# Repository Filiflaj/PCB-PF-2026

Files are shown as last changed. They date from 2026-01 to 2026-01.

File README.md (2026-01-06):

# PF 2026 - Sparkling LED Greeting Card

A custom-designed PCB created as a unique "Pour Féliciter 2026" (Happy New Year 2026) greeting card. The board features **39 individually addressable LEDs** arranged to form the text "PF 26", displaying a dynamic, warm fireworks sparkling effect.

This project is built around the **ATmega328P-AU** microcontroller, making it fully compatible with the Arduino ecosystem.

---

## 📷 Preview

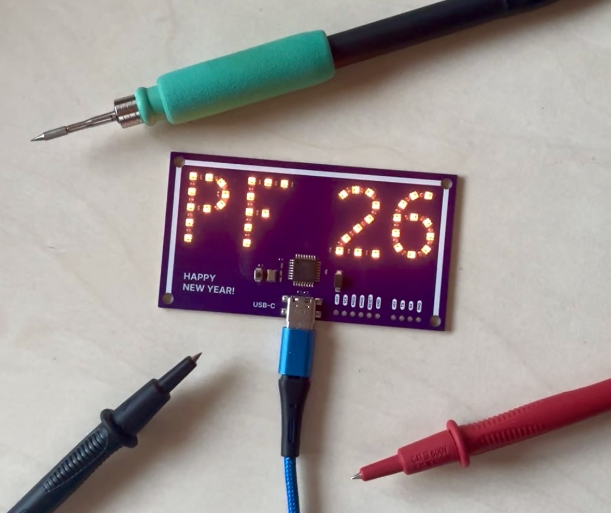
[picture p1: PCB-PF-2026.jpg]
PF 2026 Board Assembled


*Finished and assembled PCB with the sparkling effect.*

---

## ⚡ Technical Specifications

* **MCU:** ATmega328P-AU (8-bit AVR, 16MHz external crystal).
* **LEDs:** 39x WS2812B-2020 (NeoPixel) in a single chain.
* **LED Pin:** Connected to **PD3** (Digital Pin **3** in Arduino IDE).
* **Interfaces:** * Standard **ICSP** header (for bootloader and ISP programming).
    * **UART** header (RX, TX, VCC, GND, DTR) for serial communication and programming.
* **Power:** 5V via USB-C connector (with 5.1k CC resistors for compatibility).

---

## 📂 Project Structure

The repository is divided into two main sections:

### 🛠️ [HW-PF-2026](./HW-PF-2026) (Hardware)
Contains all files necessary for PCB manufacturing and assembly:
* **KiCad Project:** Full schematic and PCB layout files.
* **Schematic:** PDF version for quick reference.
* **Manufacturing:** Gerbers and Drill files.
* **BOM:** Bill of Materials.

### 💻 [FW-PF-2026](./FW-PF-2026) (Firmware)
Contains the Arduino source code:
* **Sparkle Effect:** A gentle, warm-yellow "fireworks" animation with random 1-3 LED bursts and a dim static background.
* **Library dependency:** Requires the `Adafruit_NeoPixel` library.

---

## 🔌 Programming Guide

Since the board does not have an onboard USB-to-Serial converter, you can program it using an **Arduino UNO R3** as an ISP programmer.

### 1. Wiring (Arduino UNO to ICSP)

Connect your Arduino UNO to the ICSP header on the PF 2026 board as follows:

| Arduino UNO (Programmer) | PF 2026 (Target) |
| :--- | :--- |
| 5V | VCC |
| GND | GND |
| Pin 13 | SCK |
| Pin 12 | MISO |
| Pin 11 | MOSI |
| **Pin 10** | **RESET** |

### 2. Burning the Bootloader
1.  Open Arduino IDE.
2.  Go to **File -> Examples -> 11.ArduinoISP -> ArduinoISP** and upload it to your UNO.
3.  Go to **Tools -> Board** and select **Arduino Uno**.
4.  Go to **Tools -> Programmer** and select **Arduino as ISP**.
5.  Click **Tools -> Burn Bootloader**.

### 3. Uploading Firmware
1.  Open the sketch from the `/FW-PF-2026` folder.
2.  Go to **Sketch -> Upload Using Programmer** (or press `Ctrl+Shift+U`).

---

## 👤 Author
**Filip Flajšinger** Created for the 2026 New Year celebrations. 🥂

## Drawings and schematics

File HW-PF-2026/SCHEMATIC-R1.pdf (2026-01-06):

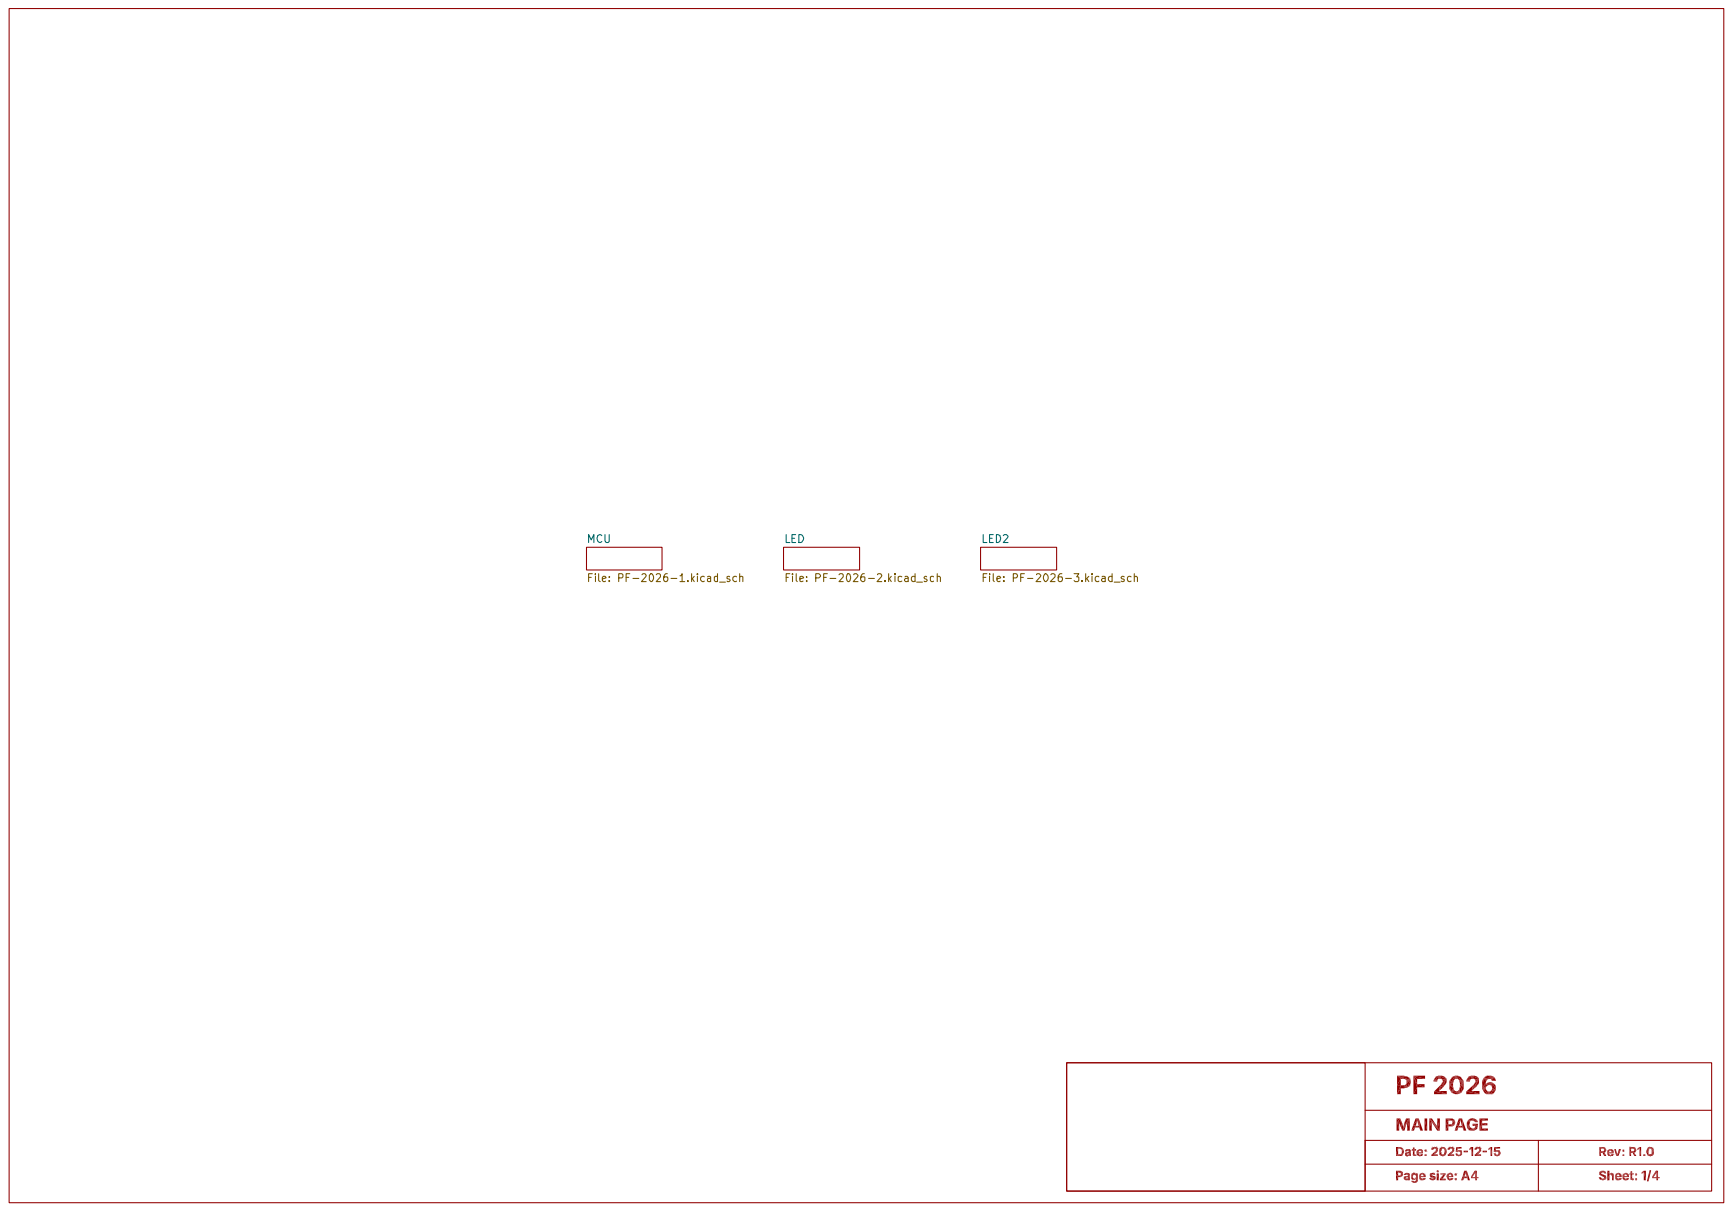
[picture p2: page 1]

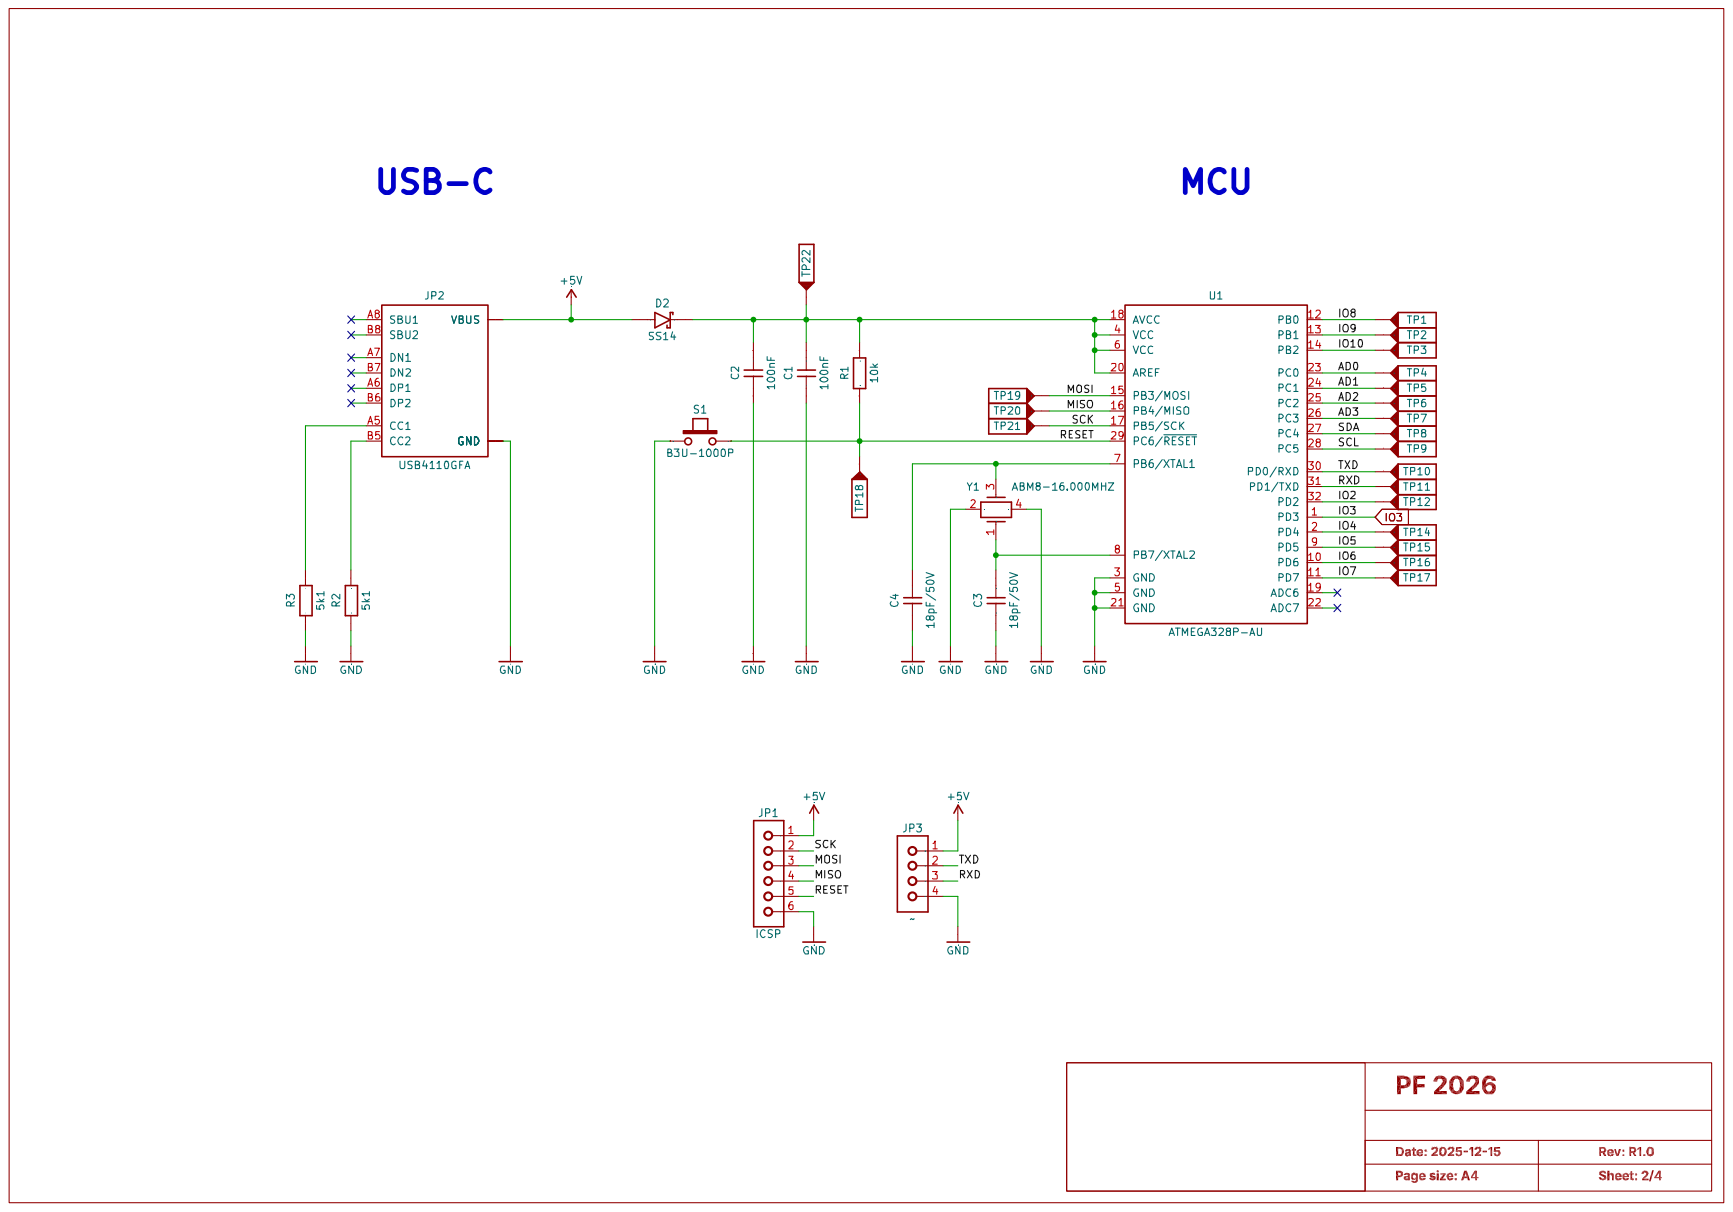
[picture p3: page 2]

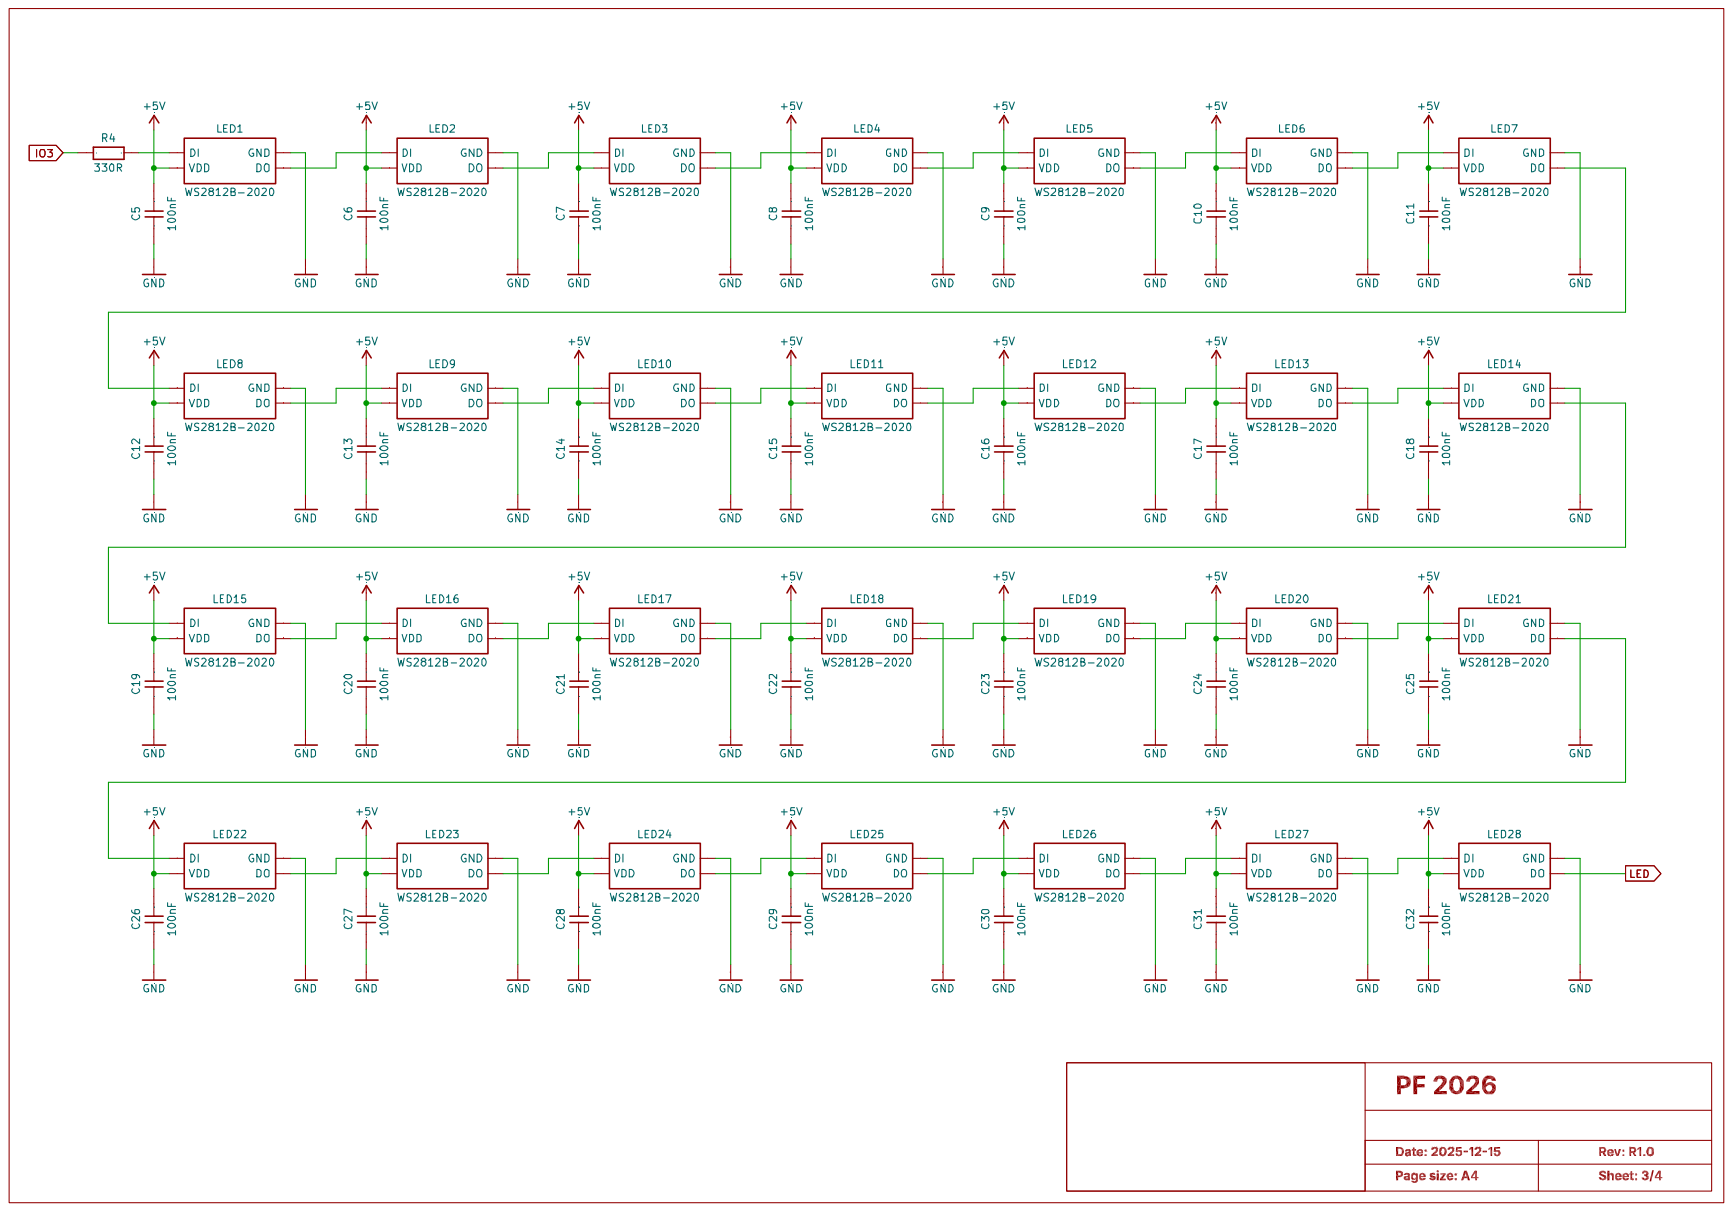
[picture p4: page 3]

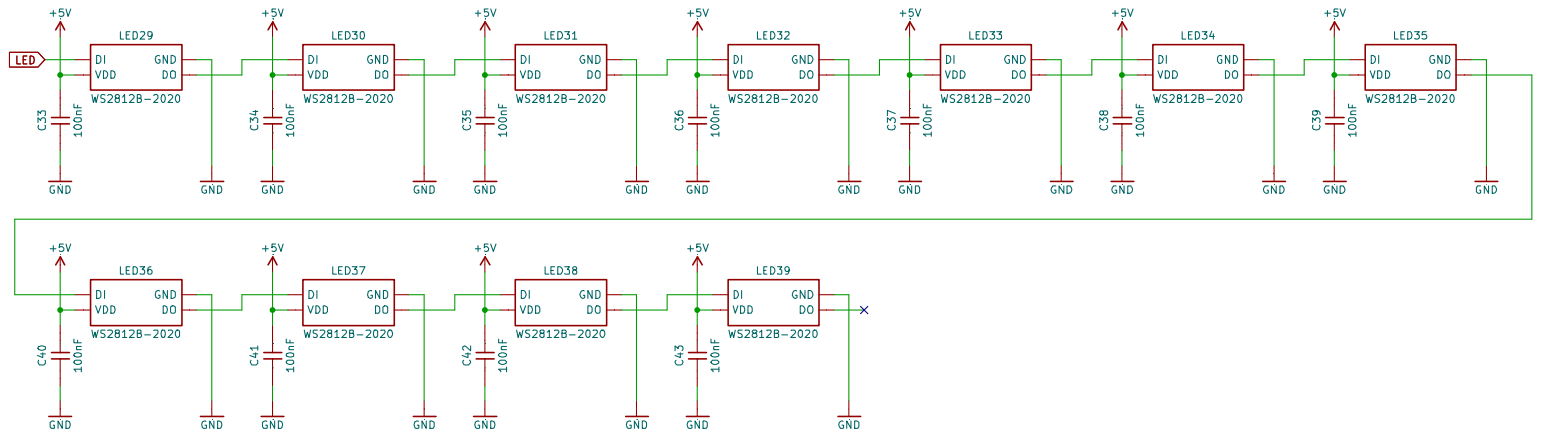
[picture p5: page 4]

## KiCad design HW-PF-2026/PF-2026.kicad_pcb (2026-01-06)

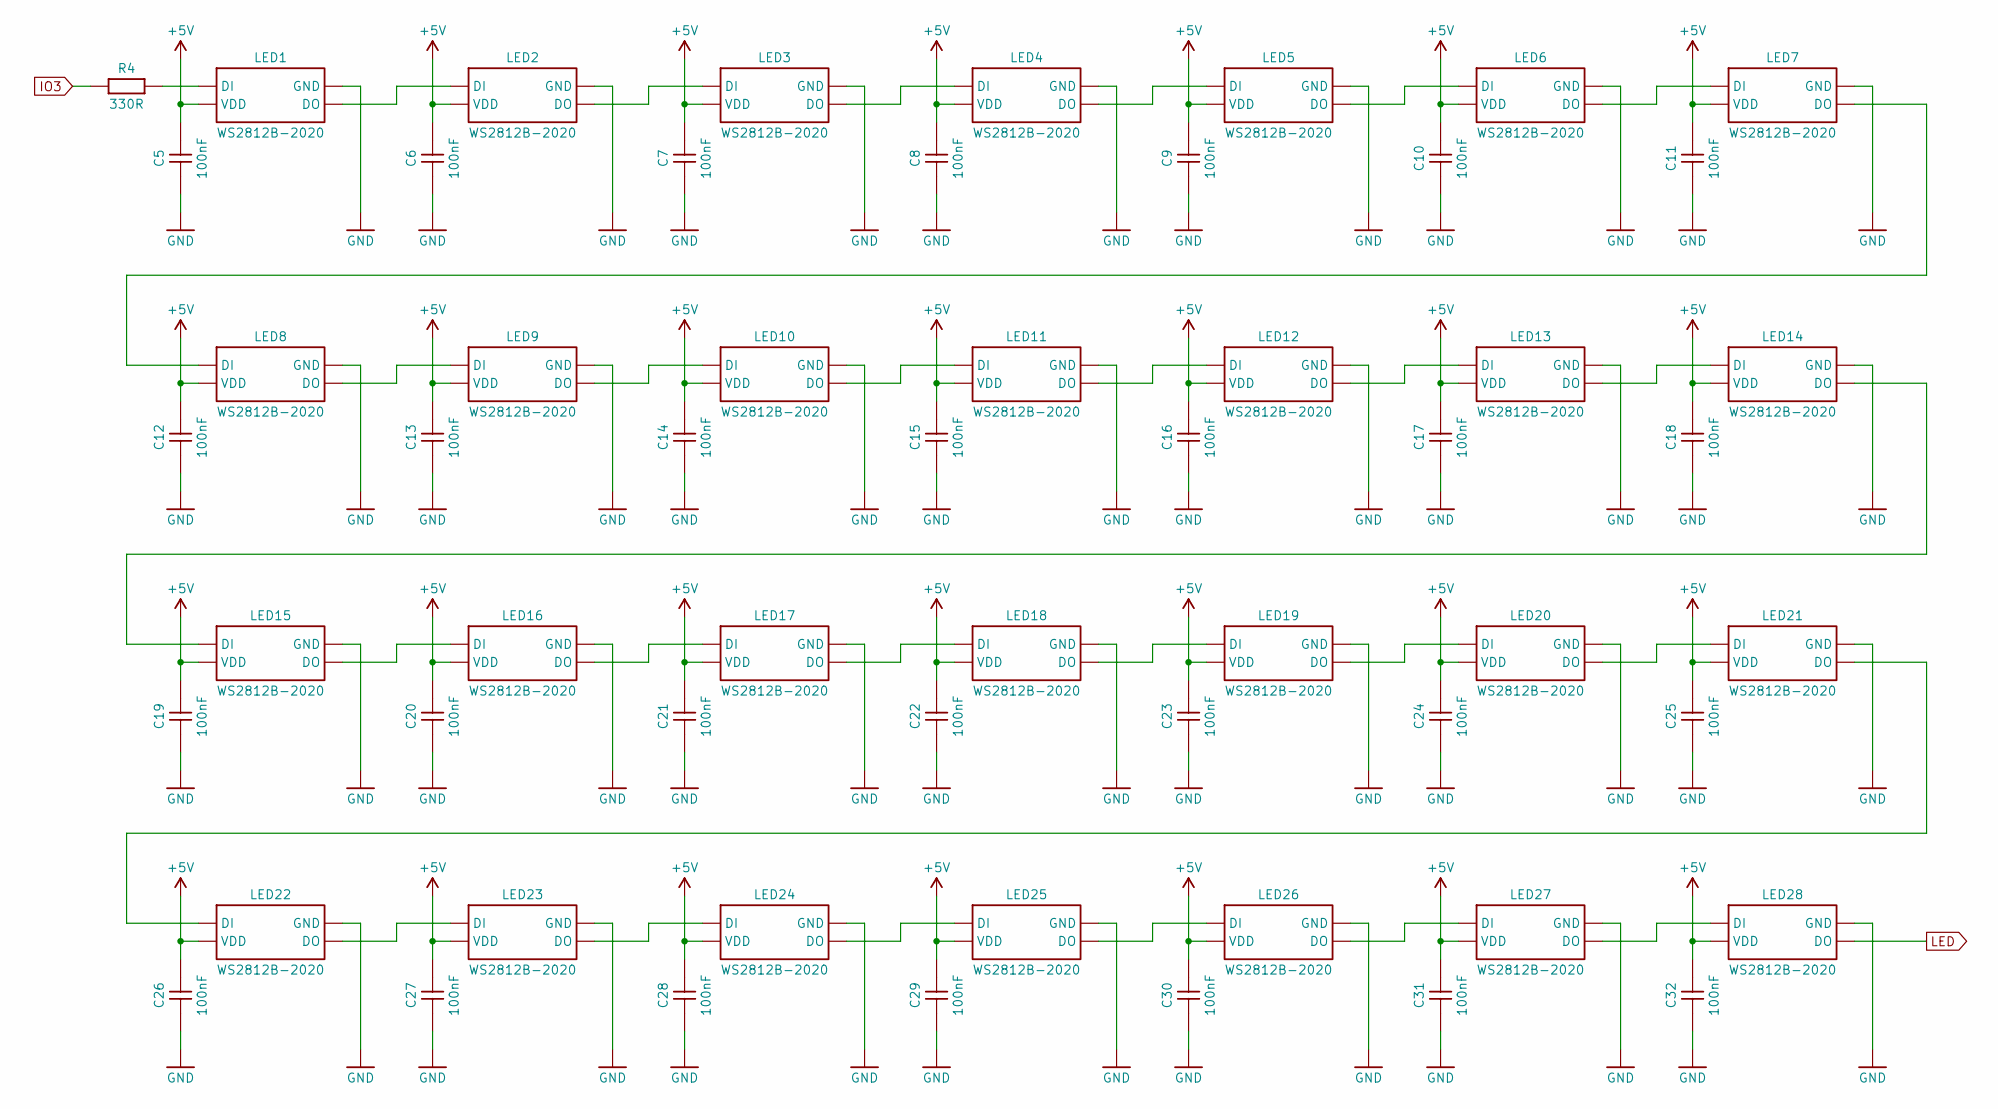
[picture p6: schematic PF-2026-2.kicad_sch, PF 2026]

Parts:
C5, C6, C7, C8, C9, C10, C11, C12, C13, C14, C15, C16, C17, C18, C19, C20, C21, C22, C23, C24, C25, C26, C27, C28, C29, C30, C31, C32: 100nF; CAPACITOR-0402_R
LED1, LED2, LED3, LED4, LED5, LED6, LED7, LED8, LED9, LED10, LED11, LED12, LED13, LED14, LED15, LED16, LED17, LED18, LED19, LED20, LED21, LED22, LED23, LED24, LED25, LED26, LED27, LED28: WS2812B-2020; WS2812B-2020_R; Manufacturer Part Number WS2812B-2020
R4: 330R; RESISTOR-0402_R; Manufacturer Part Number RT0402FRE07330RL

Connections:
+5V: C5.1, C6.1, C7.1, C8.1, C9.1, C10.1, C11.1, C12.1, C13.1, C14.1, C15.1, C16.1, C17.1, C18.1, C19.1, C20.1, C21.1, C22.1, C23.1, C24.1, C25.1, C26.1, C27.1, C28.1, C29.1, C30.1, C31.1, C32.1, LED1.4 (VDD), LED2.4 (VDD), LED3.4 (VDD), LED4.4 (VDD), LED5.4 (VDD), LED6.4 (VDD), LED7.4 (VDD), LED8.4 (VDD), LED9.4 (VDD), LED10.4 (VDD), LED11.4 (VDD), LED12.4 (VDD), LED13.4 (VDD), LED14.4 (VDD), LED15.4 (VDD), LED16.4 (VDD), LED17.4 (VDD), LED18.4 (VDD), LED19.4 (VDD), LED20.4 (VDD), LED21.4 (VDD), LED22.4 (VDD), LED23.4 (VDD), LED24.4 (VDD), LED25.4 (VDD), LED26.4 (VDD), LED27.4 (VDD), LED28.4 (VDD); also elsewhere on the board
GND: C5.2, C6.2, C7.2, C8.2, C9.2, C10.2, C11.2, C12.2, C13.2, C14.2, C15.2, C16.2, C17.2, C18.2, C19.2, C20.2, C21.2, C22.2, C23.2, C24.2, C25.2, C26.2, C27.2, C28.2, C29.2, C30.2, C31.2, C32.2, LED1.2 (GND), LED2.2 (GND), LED3.2 (GND), LED4.2 (GND), LED5.2 (GND), LED6.2 (GND), LED7.2 (GND), LED8.2 (GND), LED9.2 (GND), LED10.2 (GND), LED11.2 (GND), LED12.2 (GND), LED13.2 (GND), LED14.2 (GND), LED15.2 (GND), LED16.2 (GND), LED17.2 (GND), LED18.2 (GND), LED19.2 (GND), LED20.2 (GND), LED21.2 (GND), LED22.2 (GND), LED23.2 (GND), LED24.2 (GND), LED25.2 (GND), LED26.2 (GND), LED27.2 (GND), LED28.2 (GND); also elsewhere on the board
IO3: R4.1; also elsewhere on the board
LED: LED28.1 (DO); also elsewhere on the board
unnamed: LED1.3 (DI), R4.2
unnamed: LED1.1 (DO), LED2.3 (DI)
unnamed: LED2.1 (DO), LED3.3 (DI)
unnamed: LED3.1 (DO), LED4.3 (DI)
unnamed: LED4.1 (DO), LED5.3 (DI)
unnamed: LED5.1 (DO), LED6.3 (DI)
unnamed: LED6.1 (DO), LED7.3 (DI)
unnamed: LED7.1 (DO), LED8.3 (DI)
unnamed: LED8.1 (DO), LED9.3 (DI)
unnamed: LED9.1 (DO), LED10.3 (DI)
unnamed: LED10.1 (DO), LED11.3 (DI)
unnamed: LED11.1 (DO), LED12.3 (DI)
unnamed: LED12.1 (DO), LED13.3 (DI)
unnamed: LED13.1 (DO), LED14.3 (DI)
unnamed: LED14.1 (DO), LED15.3 (DI)
unnamed: LED15.1 (DO), LED16.3 (DI)
unnamed: LED16.1 (DO), LED17.3 (DI)
unnamed: LED17.1 (DO), LED18.3 (DI)
unnamed: LED18.1 (DO), LED19.3 (DI)
unnamed: LED19.1 (DO), LED20.3 (DI)
unnamed: LED20.1 (DO), LED21.3 (DI)
unnamed: LED21.1 (DO), LED22.3 (DI)
unnamed: LED22.1 (DO), LED23.3 (DI)
unnamed: LED23.1 (DO), LED24.3 (DI)
unnamed: LED24.1 (DO), LED25.3 (DI)
unnamed: LED25.1 (DO), LED26.3 (DI)
unnamed: LED26.1 (DO), LED27.3 (DI)
unnamed: LED27.1 (DO), LED28.3 (DI)

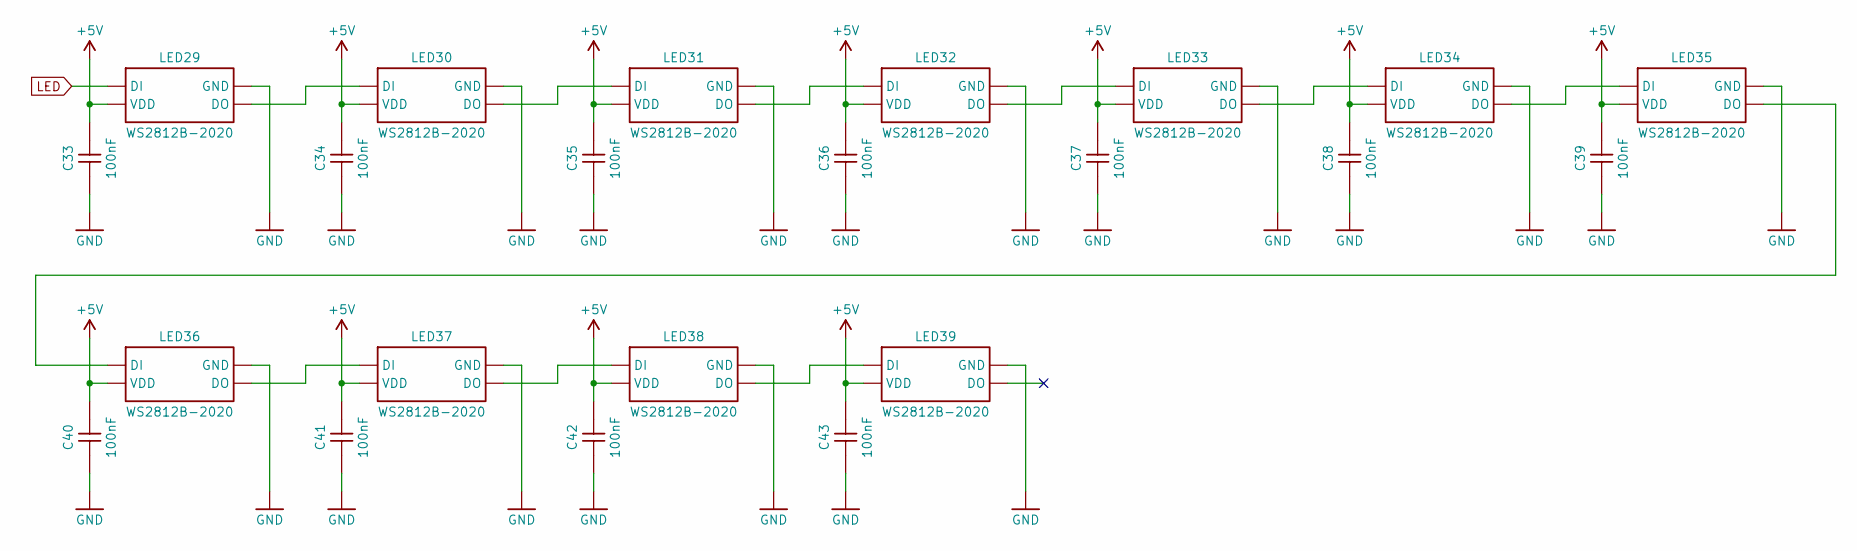
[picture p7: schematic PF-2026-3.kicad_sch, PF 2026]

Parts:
C33, C34, C35, C36, C37, C38, C39, C40, C41, C42, C43: 100nF; CAPACITOR-0402_R
LED29, LED30, LED31, LED32, LED33, LED34, LED35, LED36, LED37, LED38, LED39: WS2812B-2020; WS2812B-2020_R; Manufacturer Part Number WS2812B-2020

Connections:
+5V: C33.1, C34.1, C35.1, C36.1, C37.1, C38.1, C39.1, C40.1, C41.1, C42.1, C43.1, LED29.4 (VDD), LED30.4 (VDD), LED31.4 (VDD), LED32.4 (VDD), LED33.4 (VDD), LED34.4 (VDD), LED35.4 (VDD), LED36.4 (VDD), LED37.4 (VDD), LED38.4 (VDD), LED39.4 (VDD); also elsewhere on the board
GND: C33.2, C34.2, C35.2, C36.2, C37.2, C38.2, C39.2, C40.2, C41.2, C42.2, C43.2, LED29.2 (GND), LED30.2 (GND), LED31.2 (GND), LED32.2 (GND), LED33.2 (GND), LED34.2 (GND), LED35.2 (GND), LED36.2 (GND), LED37.2 (GND), LED38.2 (GND), LED39.2 (GND); also elsewhere on the board
LED: LED29.3 (DI); also elsewhere on the board
unnamed: LED29.1 (DO), LED30.3 (DI)
unnamed: LED30.1 (DO), LED31.3 (DI)
unnamed: LED31.1 (DO), LED32.3 (DI)
unnamed: LED32.1 (DO), LED33.3 (DI)
unnamed: LED33.1 (DO), LED34.3 (DI)
unnamed: LED34.1 (DO), LED35.3 (DI)
unnamed: LED35.1 (DO), LED36.3 (DI)
unnamed: LED36.1 (DO), LED37.3 (DI)
unnamed: LED37.1 (DO), LED38.3 (DI)
unnamed: LED38.1 (DO), LED39.3 (DI)

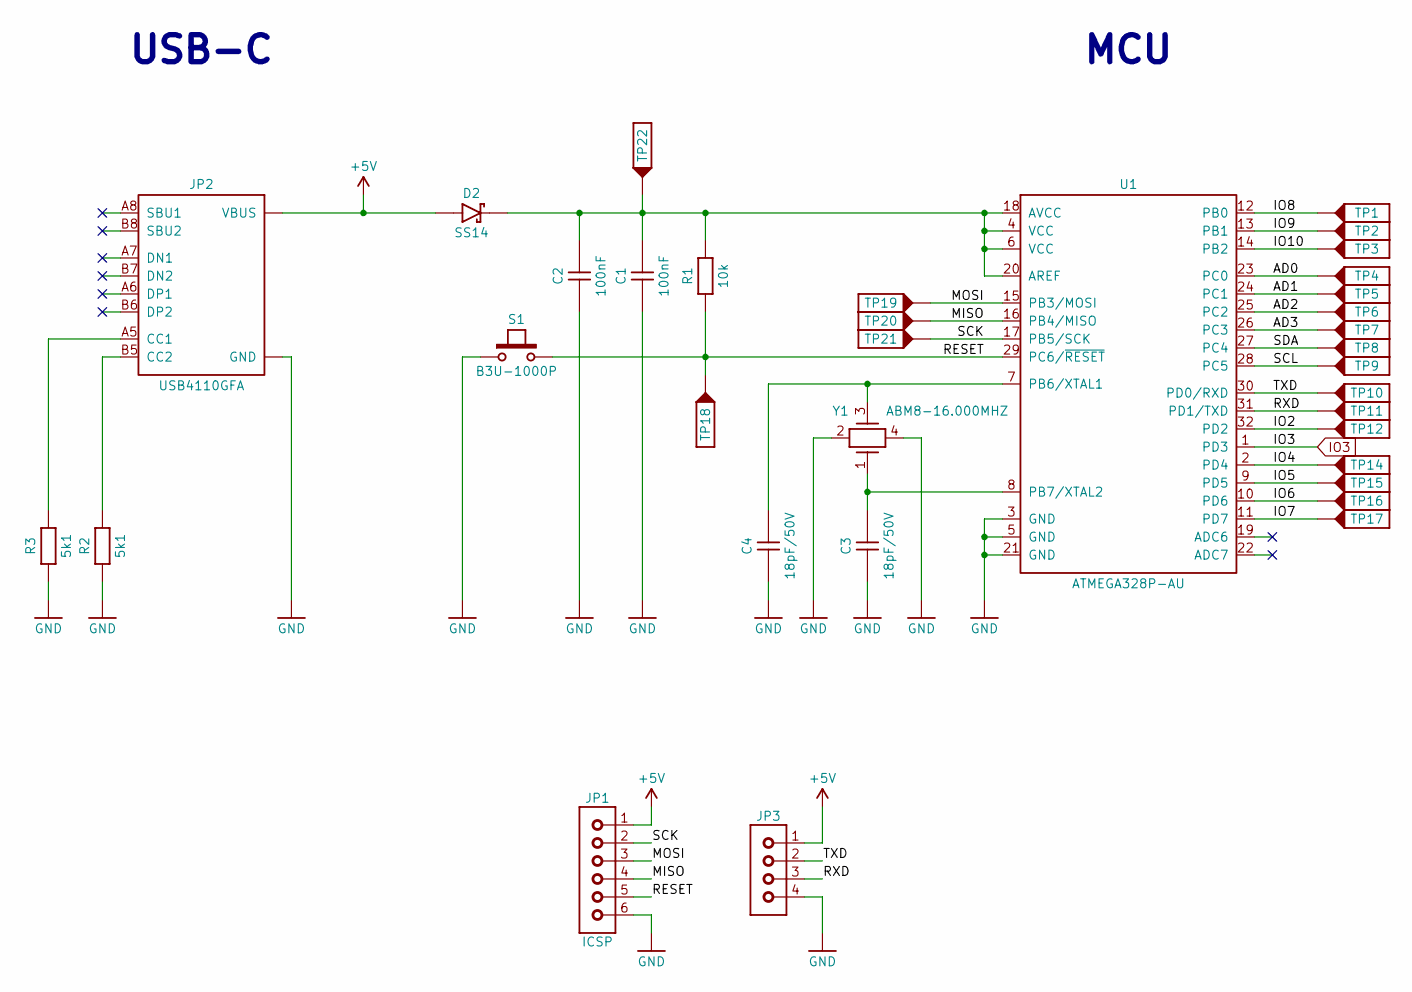
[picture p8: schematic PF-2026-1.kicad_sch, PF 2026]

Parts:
C1, C2: 100nF; CAPACITOR-0402_R
C3, C4: 18pF/50V; CAPACITOR-0402_R; Manufacturer Part Number 04025A180JAT4A
D2: SS14; SS14_R
JP1: ICSP; HEADER-6-PIN-THT; Manufacturer Part Number 61300611121
JP2: USB4110GFA; USB4110GFA_R; Manufacturer Part Number USB4110-GF-A
JP3: HEADER-4-PIN-THT; Manufacturer Part Number 61300411121
R1: 10k; RESISTOR-0402_R; Manufacturer Part Number RT0402FRE0710KL
R2, R3: 5k1; RESISTOR-0402_R
S1: B3U-1000P; B3U-1000P_R; Manufacturer Part Number B3U-1000P
TP1, TP2, TP3, TP4, TP5, TP6, TP7, TP8, TP9, TP10, TP11, TP12, TP14, TP15, TP16, TP17, TP18, TP19, TP20, TP21, TP22: TP-1.0-MM
U1: ATMEGA328P-AU; ATMEGA328P-AU_R
Y1: ABM8-16.000MHZ; ABM8-16.000MHZ-7-1-U-T_R; Manufacturer Part Number ABM8-16.000MHZ-7-1-U-T

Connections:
+5V: D2.2, JP1.1, JP2.A4/B9 (VBUS), JP2.B4/A9 (VBUS), JP3.1; also elsewhere on the board
/MCU/AD0: TP4.0, U1.23 (PC0)
/MCU/AD1: TP5.0, U1.24 (PC1)
/MCU/AD2: TP6.0, U1.25 (PC2)
/MCU/AD3: TP7.0, U1.26 (PC3)
/MCU/IO2: TP12.0, U1.32 (PD2)
/MCU/IO4: TP14.0, U1.2 (PD4)
/MCU/IO5: TP15.0, U1.9 (PD5)
/MCU/IO6: TP16.0, U1.10 (PD6)
/MCU/IO7: TP17.0, U1.11 (PD7)
/MCU/IO8: TP1.0, U1.12 (PB0)
/MCU/IO9: TP2.0, U1.13 (PB1)
/MCU/IO10: TP3.0, U1.14 (PB2)
/MCU/MISO: JP1.4, TP20.0, U1.16 (PB4/MISO)
/MCU/MOSI: JP1.3, TP19.0, U1.15 (PB3/MOSI)
/MCU/RESET: JP1.5, R1.1, S1.2, TP18.0, U1.29 (PC6/~RESET)
/MCU/RXD: JP3.3, TP11.0, U1.31 (PD1/TXD)
/MCU/SCK: JP1.2, TP21.0, U1.17 (PB5/SCK)
/MCU/SCL: TP9.0, U1.28 (PC5)
/MCU/SDA: TP8.0, U1.27 (PC4)
/MCU/TXD: JP3.2, TP10.0, U1.30 (PD0/RXD)
GND: C1.2, C2.2, C3.2, C4.2, JP1.6, JP2.A1/B12 (GND), JP2.B1/A12 (GND), JP2.S1 (GND), JP2.S2 (GND), JP2.S3 (GND), JP2.S4 (GND), JP3.4, R2.2, R3.2, S1.1, U1.3 (GND), U1.5 (GND), U1.21 (GND), Y1.2 (GND1), Y1.4 (GND2); also elsewhere on the board
IO3: U1.1 (PD3); also elsewhere on the board
unnamed: JP2.A5 (CC1), R3.1
unnamed: JP2.B5 (CC2), R2.1
unnamed: C1.1, C2.1, D2.1, R1.2, TP22.0, U1.4 (VCC), U1.6 (VCC), U1.18 (AVCC), U1.20 (AREF)
unnamed: C4.1, U1.7 (PB6/XTAL1), Y1.3 (Y2)
unnamed: C3.1, U1.8 (PB7/XTAL2), Y1.1 (Y1)

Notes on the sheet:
MCU
USB-C

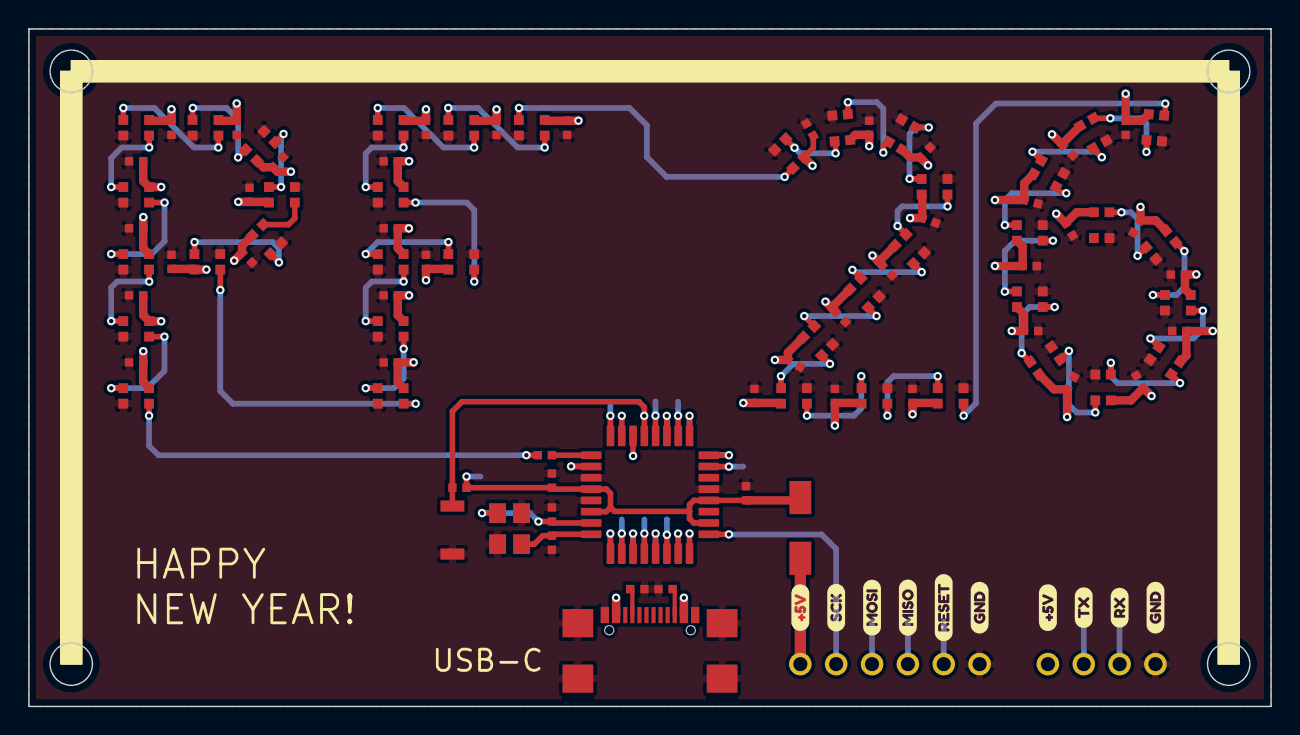
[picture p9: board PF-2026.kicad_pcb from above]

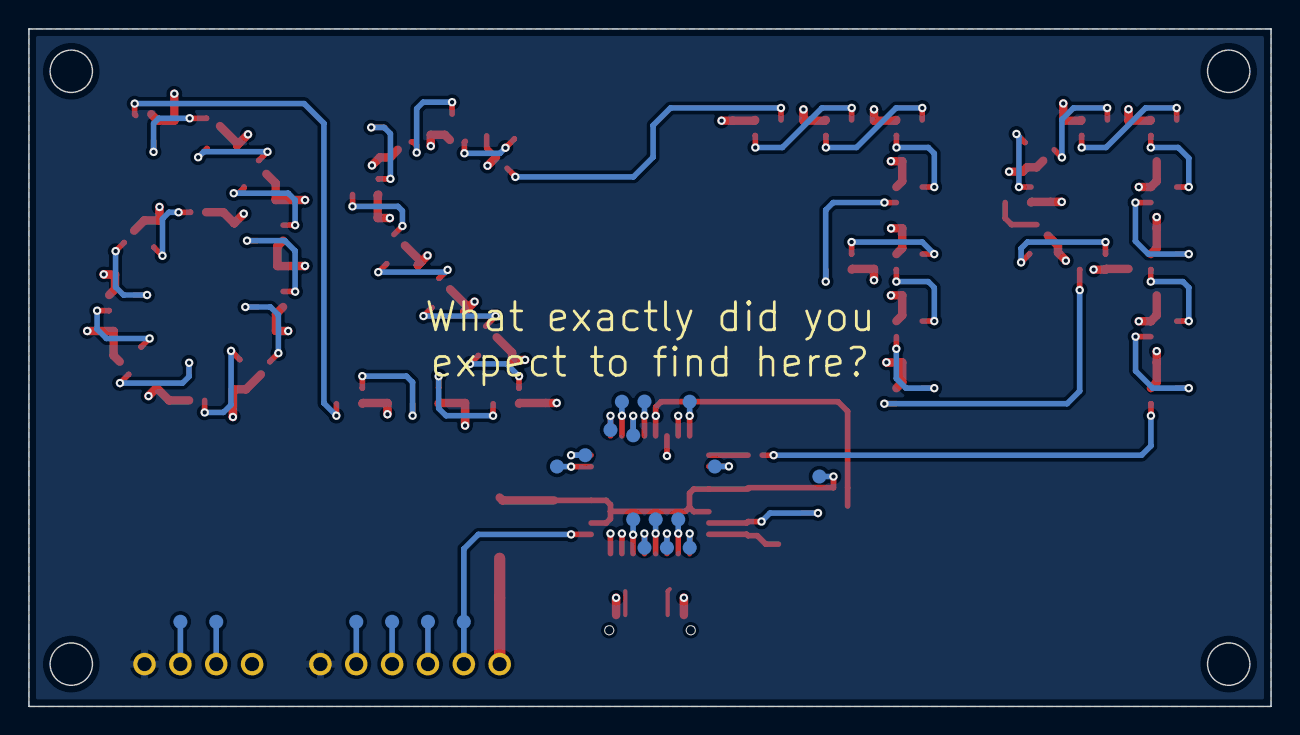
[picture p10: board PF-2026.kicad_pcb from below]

Board: 4 copper layers, 88.0 x 48.0 mm, 124 parts (21 on the bottom side), 67 nets.

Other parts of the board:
kibuzzard-69414ECA, kibuzzard-69414ECA#2: G***; kibuzzard-69414ECA
kibuzzard-69414EE3: G***; kibuzzard-69414EE3
kibuzzard-69414EEA: G***; kibuzzard-69414EEA
kibuzzard-69414EF3, kibuzzard-69414EF3#2: G***; kibuzzard-69414EF3
kibuzzard-69414F1E: G***; kibuzzard-69414F1E
kibuzzard-69414F2A: G***; kibuzzard-69414F2A
kibuzzard-69414F2F: G***; kibuzzard-69414F2F
kibuzzard-69414F25: G***; kibuzzard-69414F25

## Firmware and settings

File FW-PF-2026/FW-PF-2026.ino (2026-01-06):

#include <Adafruit_NeoPixel.h>

#define LED_PIN    3 
#define LED_COUNT 39 

Adafruit_NeoPixel strip(LED_COUNT, LED_PIN, NEO_GRB + NEO_KHZ800);

// --- NASTAVENÍ JASU A BAREV ---
// Pozadí: velmi tlumená žlutá (působí spíše jako teplý svit)
uint32_t barvaPozadi = strip.Color(6, 3, 0); 
// Jiskra: snížený jas (původně byl 80, teď zkusíme 30–40)
uint32_t barvaJiskry = strip.Color(20, 15, 5); 

void setup() {
  strip.begin();
  probarviPozadi();
  strip.show();
  randomSeed(analogRead(0));
}

void loop() {
  // 1. Určíme náhodný počet jisker, které se v tomto kroku objeví (1 až 3)
  int pocetJisker = random(1, 4); // random(min, max) -> max je exkluzivní, takže 1, 2 nebo 3
  
  // Pole pro uložení pozic, abychom je pak mohli snadno zhasnout
  int pozice[3];

  // 2. Vybereme náhodné pozice a rozsvítíme je
  for (int i = 0; i < pocetJisker; i++) {
    pozice[i] = random(0, LED_COUNT);
    strip.setPixelColor(pozice[i], barvaJiskry);
  }
  strip.show();
  
  // 3. Jiskry necháme svítit jen krátce
  delay(random(30, 70)); 

  // 4. Vrátíme vybrané LED zpět do barvy pozadí
  for (int i = 0; i < pocetJisker; i++) {
    strip.setPixelColor(pozice[i], barvaPozadi);
  }
  strip.show();

  // 5. Náhodná pauza do dalšího "výbuchu"
  delay(random(50, 200));
}

void probarviPozadi() {
  for(int n = 0; n < LED_COUNT; n++) {
    strip.setPixelColor(n, barvaPozadi);
  }
}

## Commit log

2025-12-15 Create KiCad project
    [PF-2026.kicad_pcb, PF-2026.kicad_sch]
2025-12-15 Edit project schematic and create PCB
    [PF-2026-1.kicad_sch, PF-2026-2.kicad_sch, PF-2026-3.kicad_sch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]
2025-12-16 Finalise PCB design
    [PF-2026-1.kicad_sch, PF-2026-2.kicad_sch, PF-2026-3.kicad_sch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]
2026-01-06 Restructure the project, Add FW
    [PF-2026-1.kicad_sch, PF-2026-2.kicad_sch, PF-2026-3.kicad_sch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]
